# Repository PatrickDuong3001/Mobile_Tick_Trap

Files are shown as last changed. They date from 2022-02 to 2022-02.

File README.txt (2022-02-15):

This group project contains multiple files: MATLAB file, OnShape files, and pdf files. 
I co-developed the MATLAB file with Ed Kelly.
In and Zak created 3D designs.
Orian prepared final documentation and poster. 

Functionality: 
- The tick trap is able to move back and forth (on a steel cable) between two points thanks to a motor driver
  that controls two gear motors. 
- Two ultrasonic sensors attached to the two sides of the trap will detect the distance between
  the trap and the endpoints. If the trap is about to collide with one of the endpoint, 
  the motor driver will rotate the gear motors in the opposite direction. 
- Two push buttons attached below the sensors serve as the failsafe in case the sensors do 
  not work properly and the trap crashes the endpoint. If that happens, the push button will send
  a signal to the motor driver so that the motor driver reverse the rotation of the gear motors. 

Components: 
- 2 ultrasonic sensors
- 2 gear motors
- 2 push buttons (bump switches)
- 1 motor driver
- 1 Arduino microcontroller

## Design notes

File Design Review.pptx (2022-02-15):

## Mobile Tick Trap Design Review

The Ticked-off Team
Edward Kelly, Orion Kalt, Patrick Duong, In Plaskett, Zachary Konieczka
November 12
ENGR 151: Introductory Design and Computing

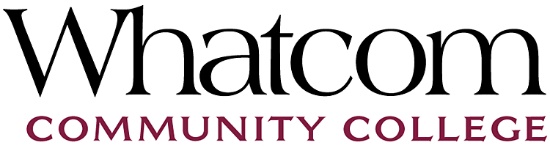
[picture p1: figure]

## Design Constraints (Updated)

Constraint Name | Description
Live ticks | The trap must keep the caught ticks alive
Design integration | Our model must integrate with the work of the previous groups
Arduino hardware | Digital, analog, and GND pins are needed
Height | Our model must stay off the ground
Power source | Must run on portable/ available power source
Durability | The system must be able to survive outdoor weather and animals that could possibly come into contact with it.

## Design Objectives (Updated)

Objective Name | Description
Adjustable height | The system is able to move up and down.
CO2 | We must have enough CO2 for at least one week before replacement
Aesthetic | The model should look nice and have a user-friendly structure. Set up should be intuitive.
Mobility | Design should have a mobility range of 10 or more feet
Visibility | The design should be visible to people or animals.
Responsive | Our model should use sensors to move back and forth between two points, and turn back if an obstacle is encountered.

Objective | Description

## Project Concept Statement

- The mobile tick trap is designed to collect living ticks for research. Adding mobility to the tick trap will be accomplished with motorized wheels mounted on the tick trap with stainless steel cable strung between ratchet straps wrapped around trees.
- Nature will provide a multitude of possible obstructions which we hope to detect with motion sensors and switches.
- This project will generate valuable knowledge for the little understood prevalence of ticks in the Pacific Northwest.

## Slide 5

Design Concept

Ratchet Straps
Tick Mop

Cable

Tick Tram

## Design Concept

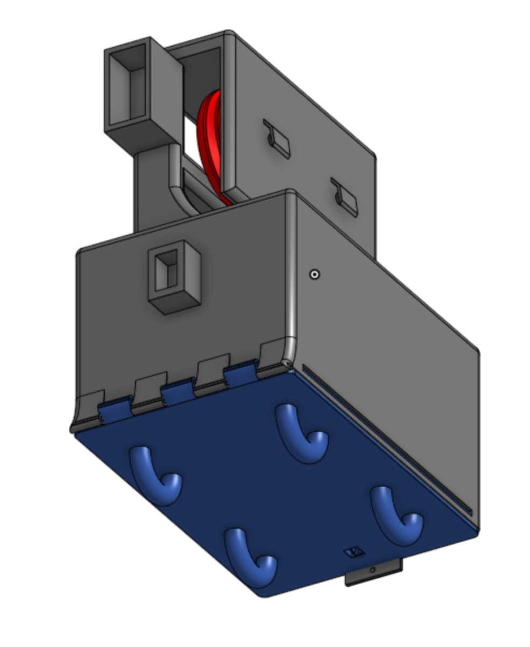
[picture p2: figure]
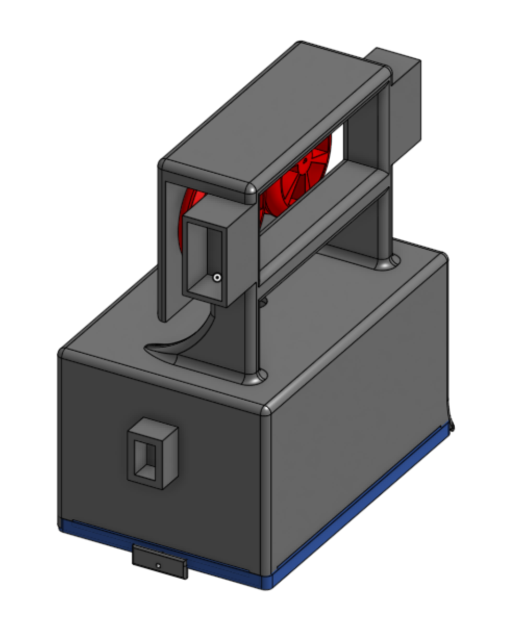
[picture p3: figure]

Sensor housing

Bump Switch housing

Wheel System and Motor housing

Loops to hang mop

## Key Features: Ultrasonic Sensors

- Attached to the front and back of trap above wire attachment
- Support the mobility of the trap by telling it when to turn around
- Mounted above wire so it's less likely to notice small obstructions that won’t impede mobility

Sensor housing

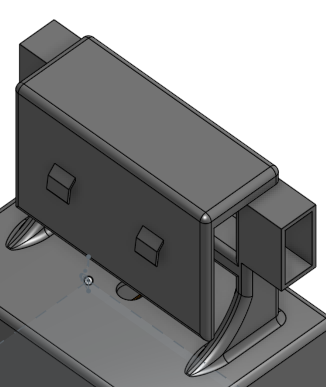
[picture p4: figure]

## Key Features: Mop and Loops

- Located at the bottom of the trap, kept by 4 loops. Helps the trap to catch more ticks within its reach.
- Visible enough for people and animals to avoid crashing into the trap (support the visibility of the trap).
- Dragged around to catch ticks.

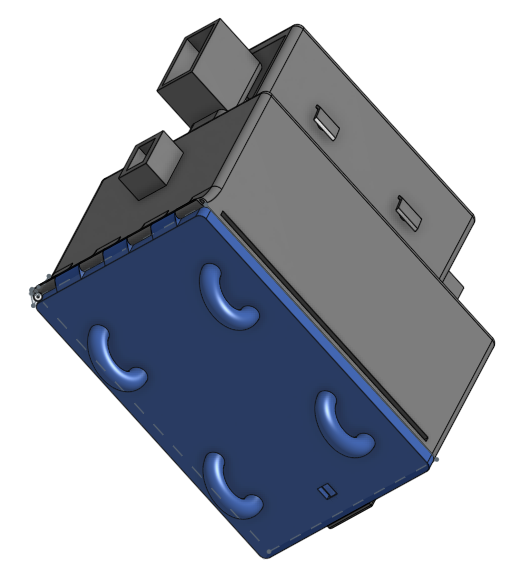
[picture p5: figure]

Loops

## Key Features: Wheel System

- Has 2 motorized wheels, both are covered. Protected from the rain by the cover.
- Imperative to the mobility of the trap. Moves back and forth based on the signal from the ultrasonic sensors.
- Moves slowly so that the ticks have time to get attracted to CO2 and caught by the mop.

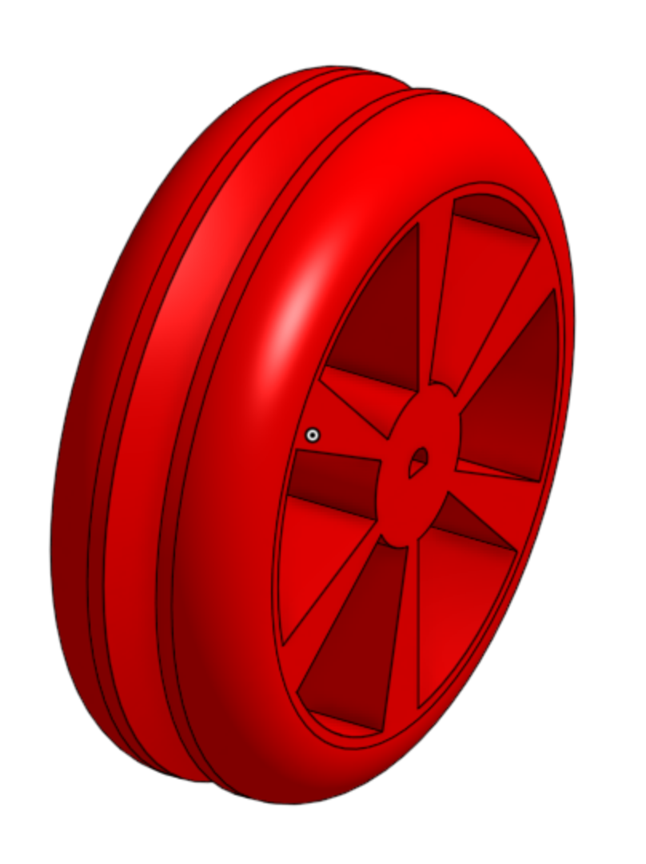
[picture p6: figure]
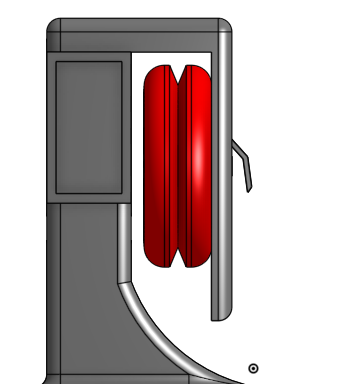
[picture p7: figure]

Indent to pinch wire

Wheel housing

## Key Features: Bump Switch

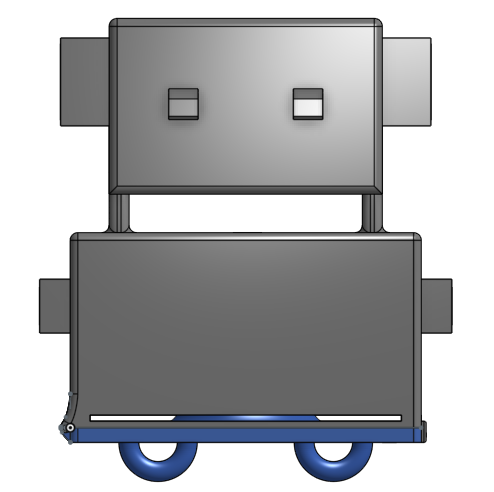
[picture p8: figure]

- Back-up if object unnoticed by ultrasonic sensor impedes movement of trap
- Serves as a failsafe for ultrasonic sensors

Bump Switch Housing

## Questions? We are also looking for your feedback.

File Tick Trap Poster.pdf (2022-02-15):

## Mobile Tick Trap Project

### Ed Kelly, Orion Kalt, Patrick Duong, In Plaskett, Zak Konieczka

Engineering 151: Introductory Design and Computing

Introduction
Tick borne lyme disease is a growing problem in North America that is predicted to increase in the Pacific Northwest as a result of climate change. Researching ticks is essential to understanding both their prevalence and the diseases they may carry. The Whatcom biology department currently has only two ticks to study, it is our goal to find more.

Design Problem
Using CO2 as bait and dragging a blanket across brush are the two most effective methods of catching ticks discovered in our research. Our design brings both of these concepts together into one system. We are working off a CO2 emitting box trap that features slits on the bottom for ticks to enter, and an environment that mimics a host animal inside. Our challenge is to integrate this trap with a mobile system. We will be stringing a trolley between two trees that the box moves across. The trap will also feature a mop hanging below that mimics the blanket dragging methods we researched.

Design Development
Our focus was adding mobility to the tick trap.We created a motorized trolley that is simple to set up and lightweight so that it is easy to travel with to remote locations. We decided to use steel cable so the wheels will grip on uniformly. Our wheels feature a cut-out section to rest over the wire that will be printed from soft plastic for grip.
We decided to use two ultrasonic sensors to detect the end of the cable. When a sensor detects the end, the motors change direction until the reaching the end again, tripping the other sensor.

Everything functions as planned: the motorized wheels rotate based on the reading of the sensors and bump switches and the power switch control the activation of the whole trap.
The only problem we ran into is the ultrasonic sensor giving false readings. To work around this we made the code pause and double check before turning around.

### Discussion and Recommendations

Our model heavily depends on the the laptop since it still requires connection between the Arduino and laptop. We would recommend the next group integrate a power supply, this will be needed for the trap to function separately from a computer.
More improvement could be made in the CO2 capacity on the trap. From the last groups designs, the CO2 cartridge would only last 24 hours. A larger tank and battery pack need to be added for the trap to remain isolated for at least a week. Also the ultrasonic sensors have been inconsistent, buying better sensors to improve the traps responsiveness may be warranted.

### Testing Results

### References

Centers for Disease Control and Prevention, National Center for Emerging and Zoonotic Infectious Diseases. (2018) Lyme Disease. Retrieved from https://www.cdc.gov/lyme/index.html

Mays, S. E., Houston, A. E., & Trout Fryxell, R. T. (2016). Comparison of novel and conventional methods of trapping ixodid ticks in the southeastern U.S.A. Medical & Veterinary Entomology, 123–134.

### Detailed Design Description

Ratchet straps are attached to two trees on either end of a metal cable strung tight between the trees. A motorized trolley with two motors and two wheels carries the tick trap and tick dragging system below the wire.
The arduino will be programmed to move slowly and incrementally along the cable. The code will pause for several minutes in each position before moving again. Through our research we learned ticks are slow so the system will pause for several minutes at a time. An ultrasonic sensor and bump switch will be featured on each side to turn the system around when it approaches the tree or if an obstacle gets in the way.

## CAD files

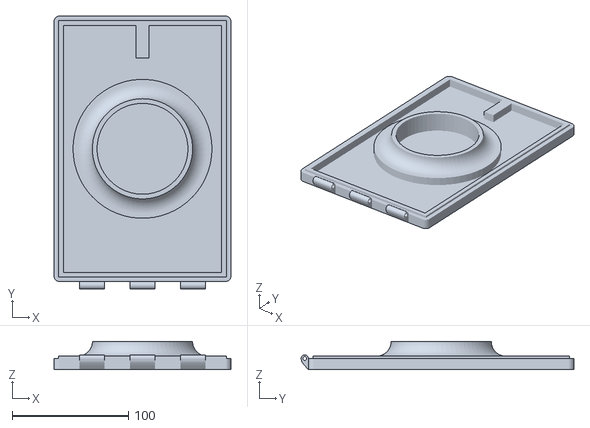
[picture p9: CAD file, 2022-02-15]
main box - Part 1.stl
152.4 x 234.9 x 24.2

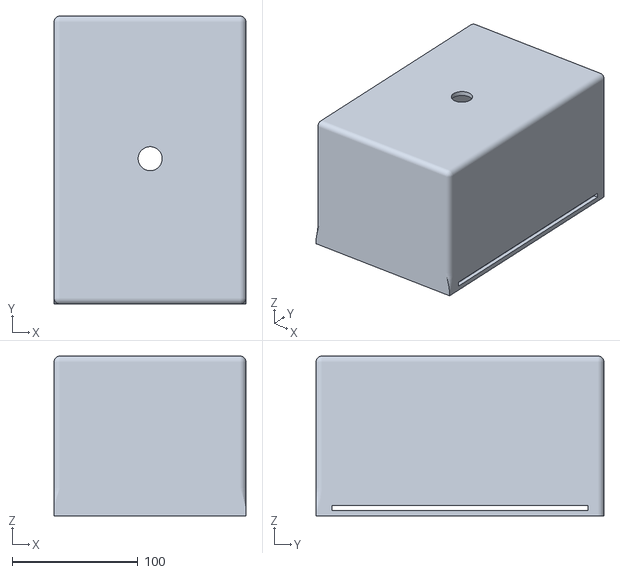
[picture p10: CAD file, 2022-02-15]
main box - Part 14.stl
152.4 x 228.6 x 127.0

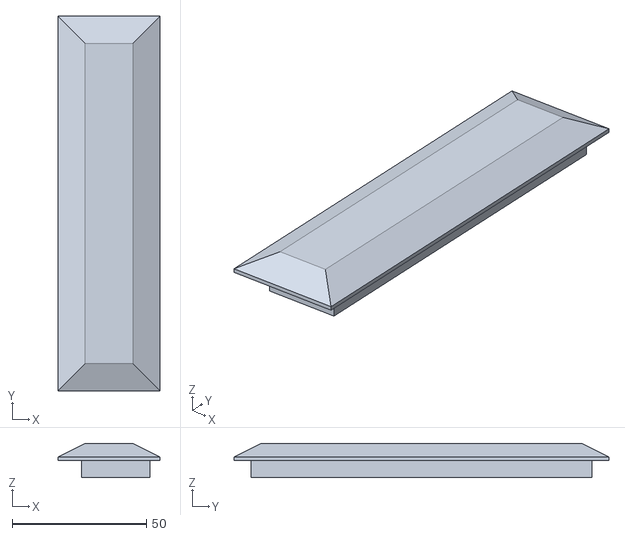
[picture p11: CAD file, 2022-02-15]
main box - Part 4.stl
38.1 x 139.7 x 12.7

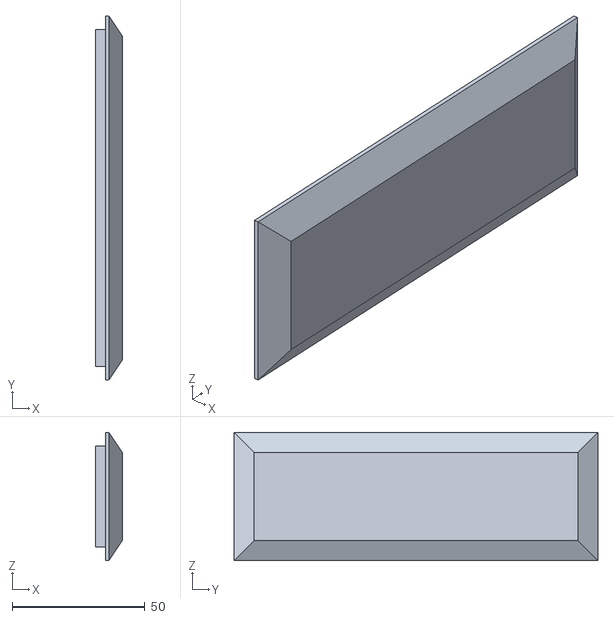
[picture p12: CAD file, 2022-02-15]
main box - Part 5.stl
10.2 x 137.2 x 48.3

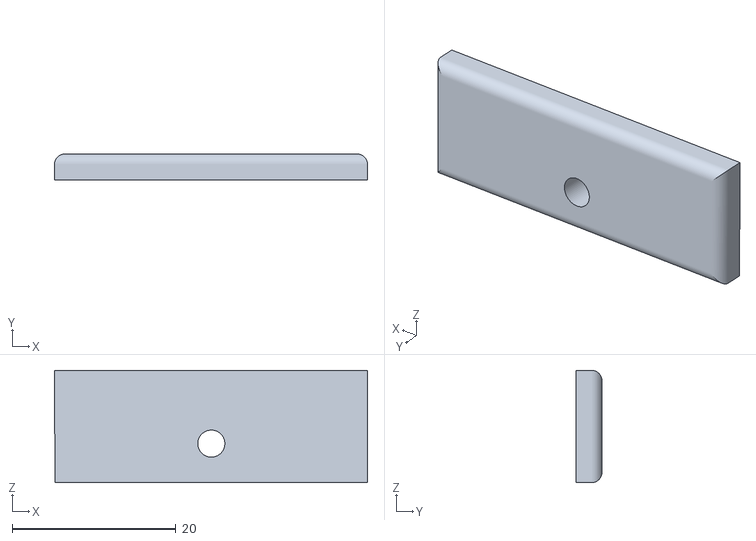
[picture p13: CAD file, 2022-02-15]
main box - Part 15.stl
38.2 x 3.18 x 13.7

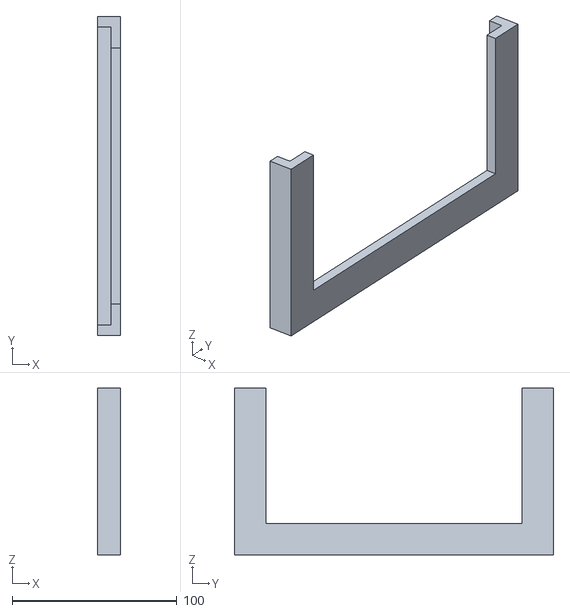
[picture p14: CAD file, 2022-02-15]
main box - Part 6.stl
14.0 x 193.5 x 101.1

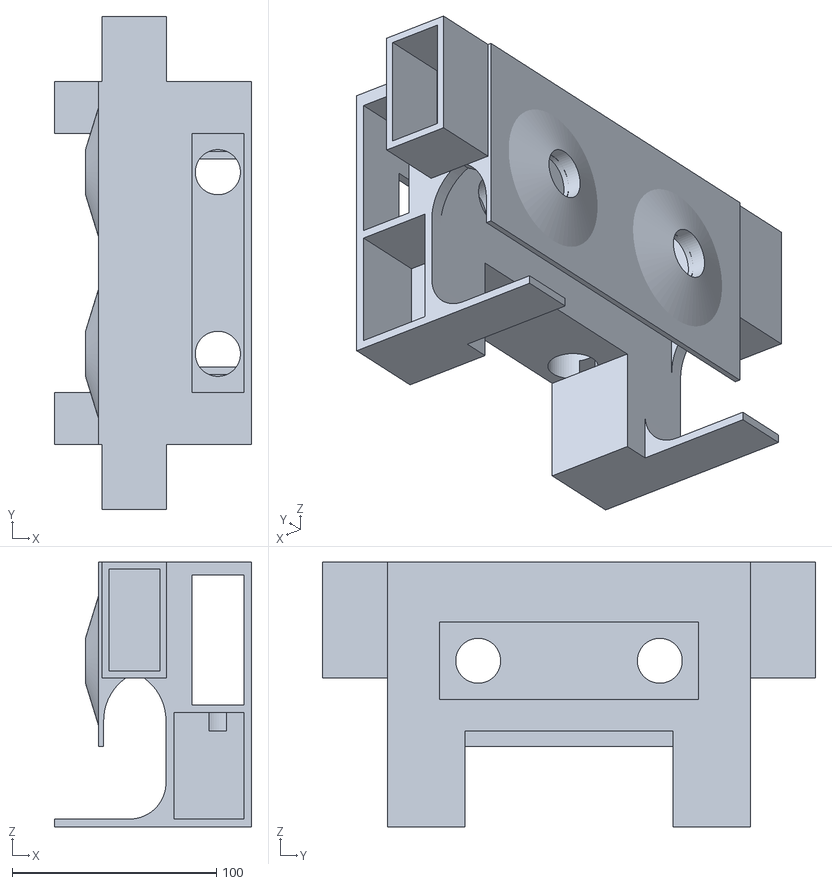
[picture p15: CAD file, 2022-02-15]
main box - Part 3.stl
96.5 x 241.3 x 129.5

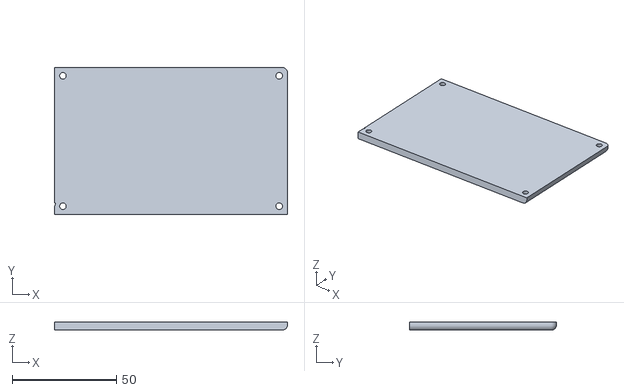
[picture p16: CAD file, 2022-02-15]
main box - Part 2.stl
112.0 x 70.7 x 4.00

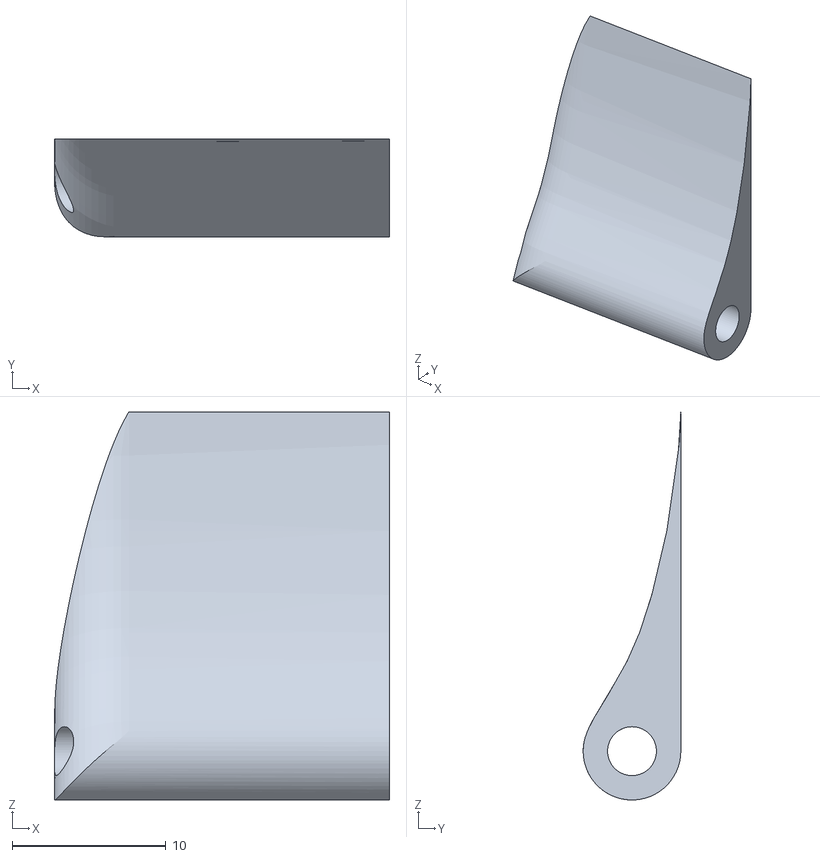
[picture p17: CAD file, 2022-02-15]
main box - Part 11.stl
21.8 x 6.35 x 25.2

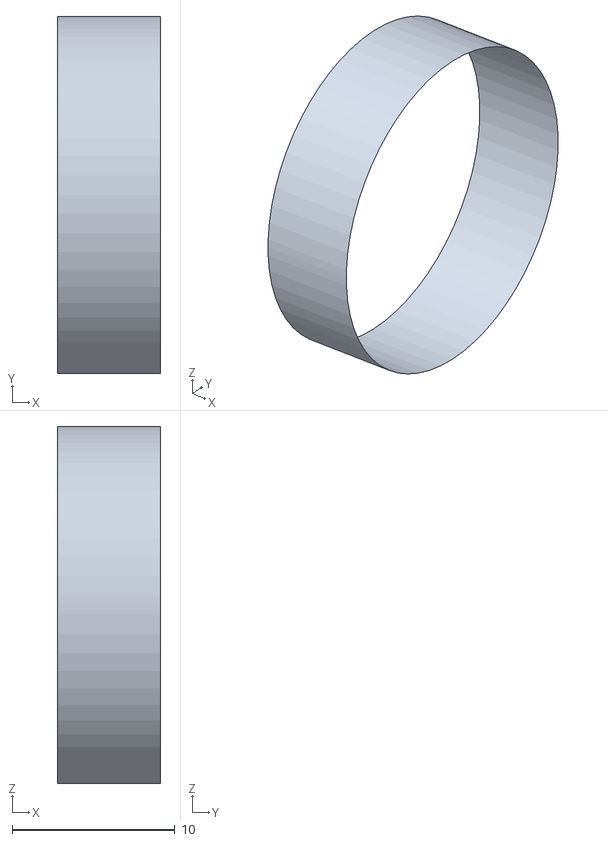
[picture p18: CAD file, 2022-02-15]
main box - Surface 1.stl
6.35 x 22.0 x 22.0

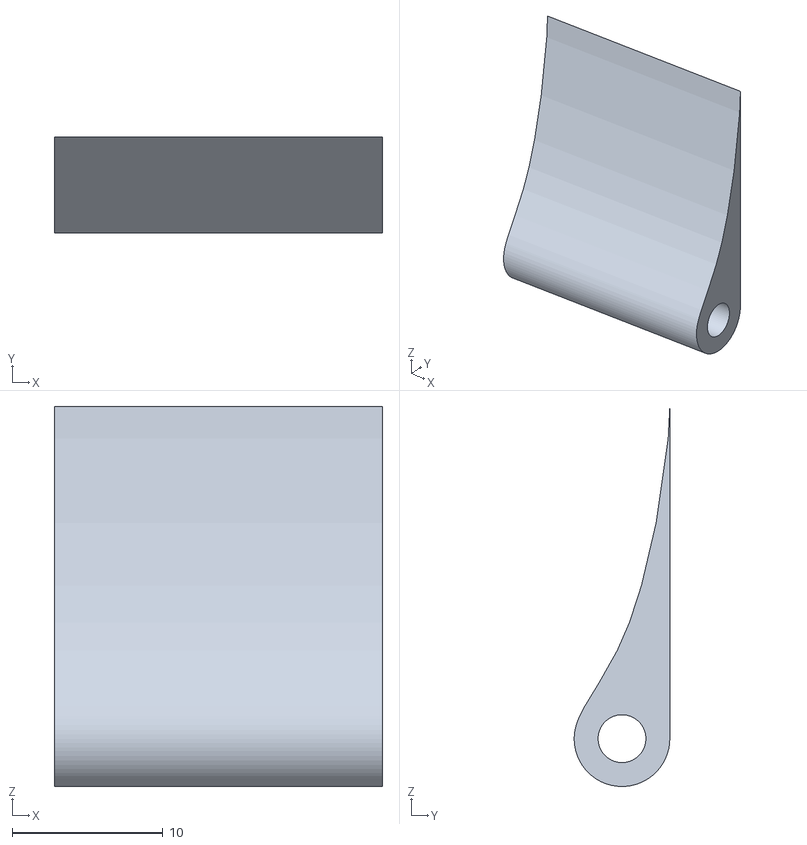
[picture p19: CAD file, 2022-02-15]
main box - Part 7.stl
21.8 x 6.35 x 25.2

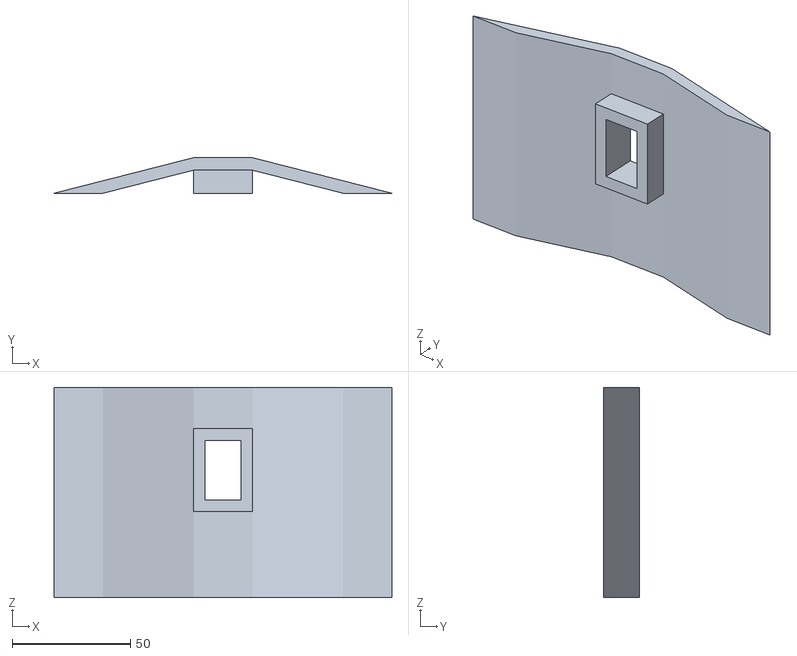
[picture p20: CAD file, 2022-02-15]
main box - Part 13.stl
142.7 x 15.0 x 88.9

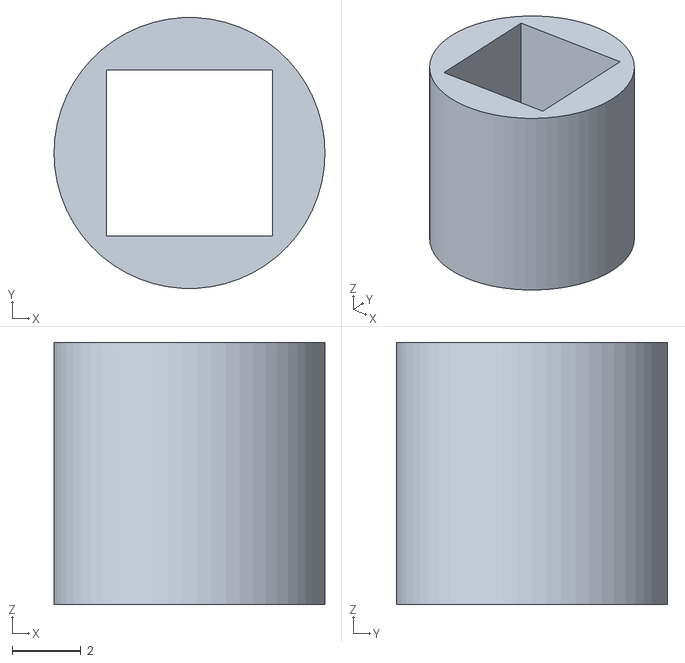
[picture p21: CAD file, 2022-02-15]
Drive Shaft - Part 2.stl
7.87 x 7.86 x 7.62

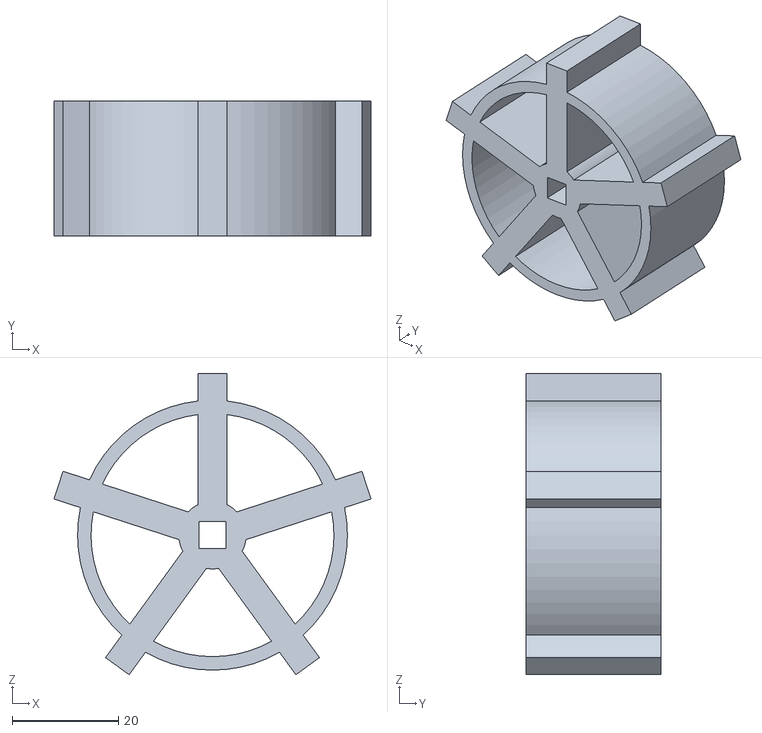
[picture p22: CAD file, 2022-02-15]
Wheel Concept - Part 2.stl
59.7 x 25.4 x 56.8

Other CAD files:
main box - Part 12.stl
main box - Part 8.stl
main box - Part 10.stl
main box - Part 9.stl
Drive Shaft - Part 1.stl
Drive Shaft - Part 3.stl
Wheel Concept - Part 1.stl
